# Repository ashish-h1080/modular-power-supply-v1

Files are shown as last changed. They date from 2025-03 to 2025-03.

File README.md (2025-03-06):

# ModuloVolt (V1.02) - modular power supply 
This modular power supply circuit provides selectable fixed and adjustable voltage outputs using LM2596 regulators. It integrates a 555 timer-based pulse generator and supports multiple operational modes via switchable configurations. The design includes high-side switching for improved isolation and safety.

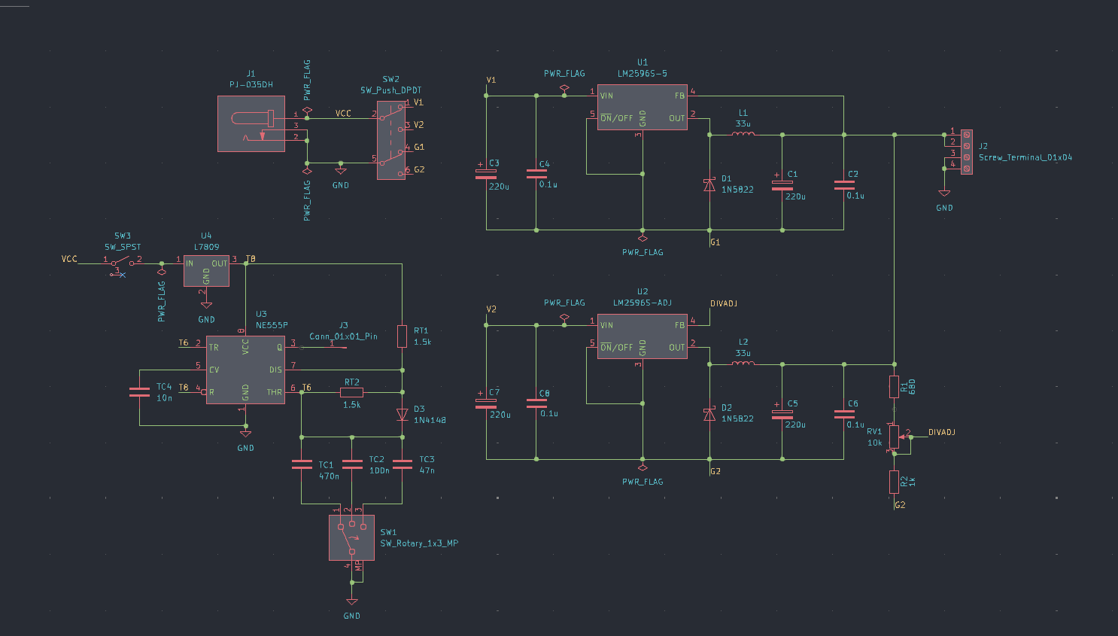
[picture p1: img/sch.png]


## Features
This modular power supply system offers a range of features designed for flexibility and reliability. It provides switchable voltage outputs, including a fixed 5V regulated supply using the LM2596-5V and an adjustable output of up to 12V via the LM2596-ADJ, controlled by a potentiometer. To ensure proper isolation and seamless switching between these voltage sources, a high-side DPDT switch is integrated into the design. Additionally, the system includes an integrated pulse generator, utilizing a 555 timer circuit to produce clock pulses. The pulse frequency can be adjusted by selecting different capacitors, making the system adaptable for various applications requiring precise timing signals.

## Implementation
The modular power supply system is designed for versatility and stability, incorporating key components for power input, regulation, filtering, and additional functionalities. A DC power jack (J1) serves as the main input source, while a DPDT switch (SW2) allows seamless selection between a fixed and an adjustable voltage regulator. The LM2596-5V (U1) ensures a stable 5V output, whereas the LM2596-ADJ (U2), controlled via a 10k potentiometer (RV1), provides a user-defined adjustable voltage. To enhance performance, capacitors (C1-C8) and inductors (L1, L2) are implemented for stability and noise reduction, while Schottky diodes (D1, D2) safeguard the system against reverse voltage. Additionally, a 555 timer (U3) functions as a pulse generator, with its frequency adjustable through capacitors (TC1-TC4) and resistors (RT1, RT2). The generated clock pulses are accessible via a single-pin connector (J3), offering expanded utility for various applications. Finally, a 4 pin terminal block (J2) efficiently distributes power and ground, ensuring easy connectivity for external circuits.

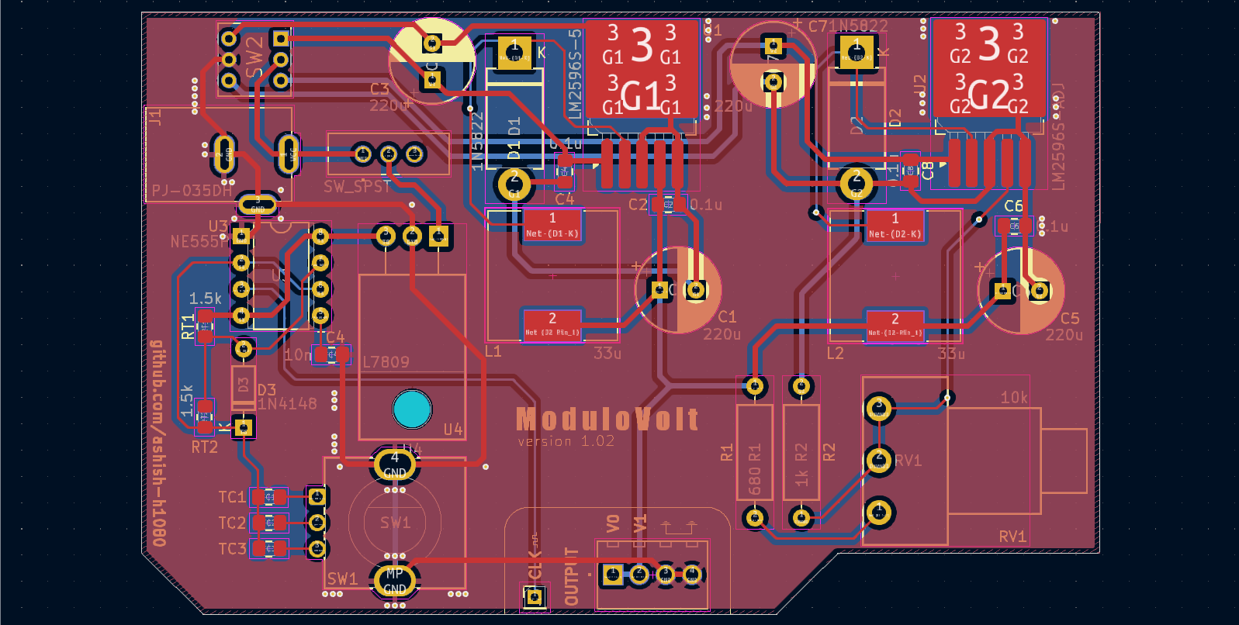
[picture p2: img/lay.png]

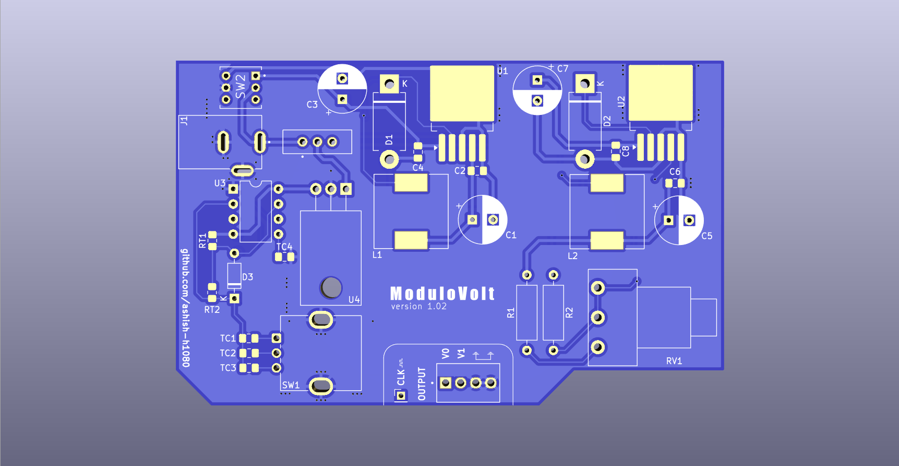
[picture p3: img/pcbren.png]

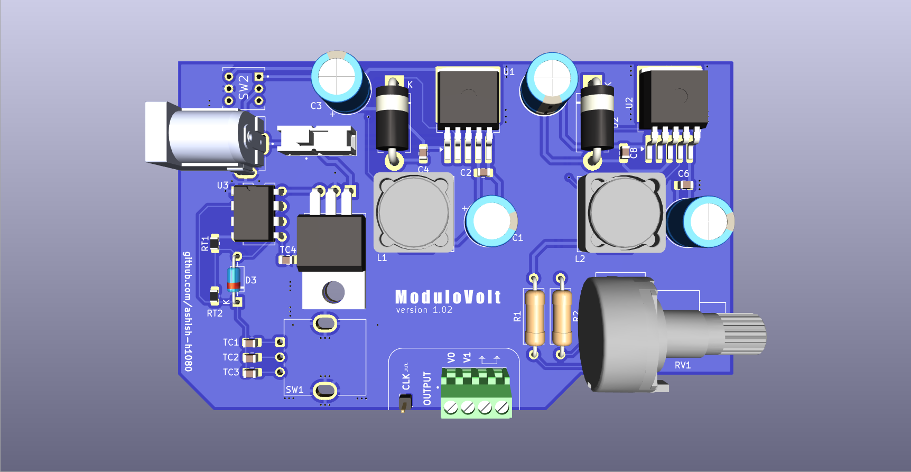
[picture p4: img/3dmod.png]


## Future Iterations
- **Onboard volt meter**
- **Additional signal processing (e.g., sine wave generator, filters, amplifiers)**
- **Microcontroller-based control for automated switching and monitoring**

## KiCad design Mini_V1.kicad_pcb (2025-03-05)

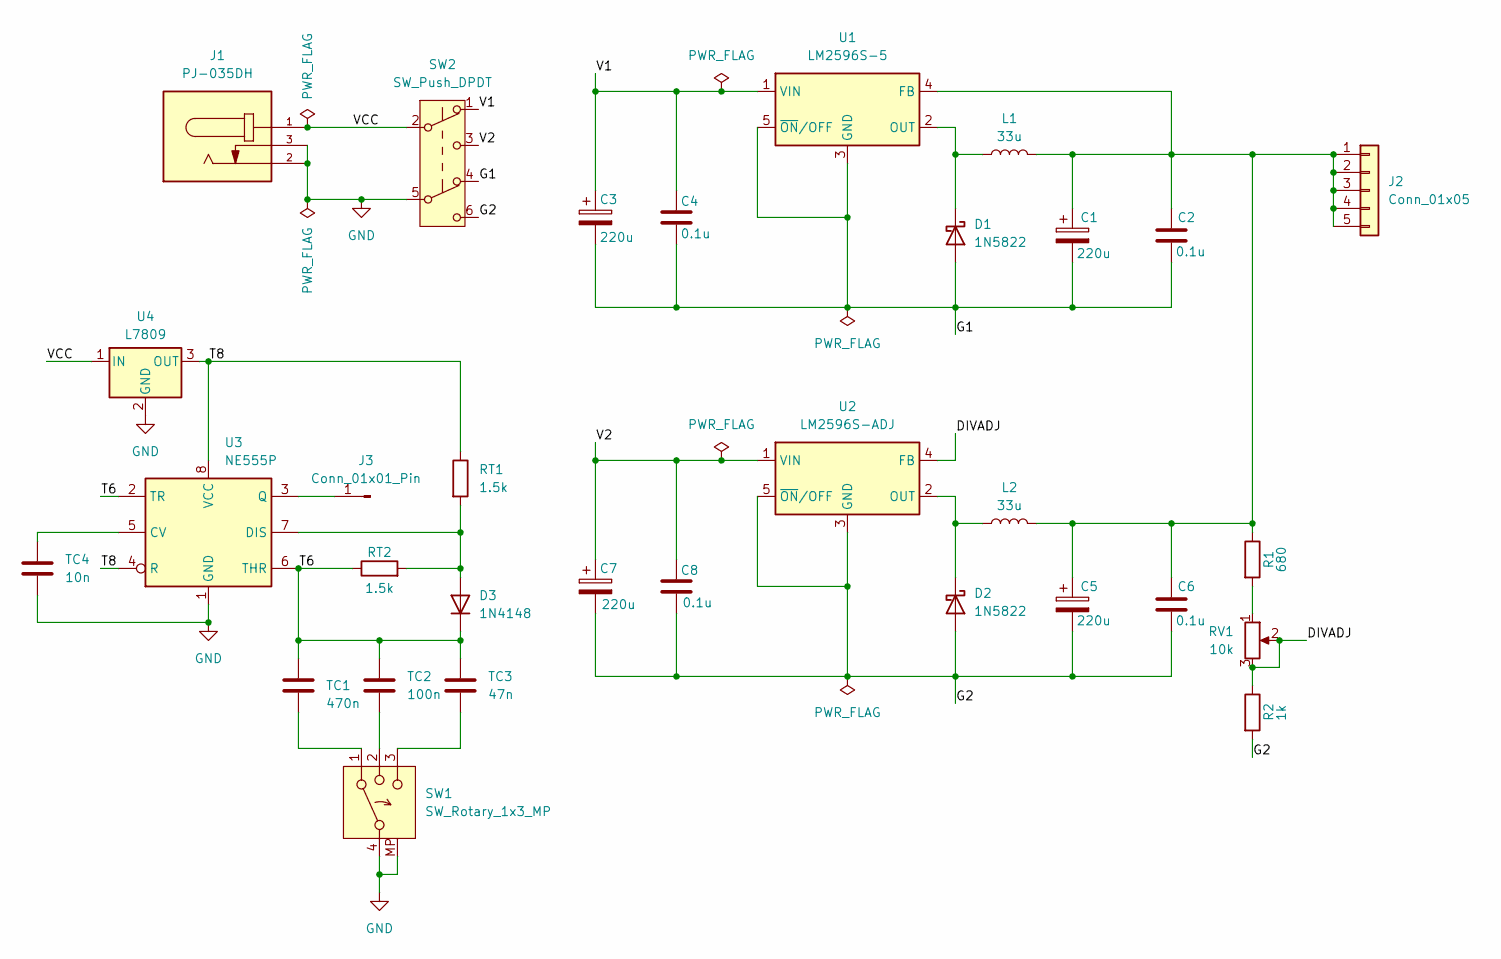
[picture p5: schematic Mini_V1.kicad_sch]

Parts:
C1, C3, C5, C7: 220u; CP_Radial_D8.0mm_P3.50mm
C2, C4, C6, C8: 0.1u; C_0805_2012Metric_Pad1.18x1.45mm_HandSolder
D1, D2: 1N5822; D_DO-201AD_P12.70mm_Horizontal
D3: 1N4148; D_DO-35_SOD27_P7.62mm_Horizontal
J1: PJ-035DH; CUI_PJ-035DH; PARTREV 1.05
J2: Conn_01x05; PinHeader_1x05_P2.00mm_Vertical
J3: Conn_01x01_Pin; PinHeader_1x01_P2.00mm_Vertical
L1, L2: 33u; INDP125125X600N
R1: 680; R_Axial_DIN0309_L9.0mm_D3.2mm_P12.70mm_Horizontal
R2: 1k; R_Axial_DIN0309_L9.0mm_D3.2mm_P12.70mm_Horizontal
RT1, RT2: 1.5k; R_0805_2012Metric_Pad1.20x1.40mm_HandSolder
RV1: 10k; Potentiometer_Piher_PC-16_Single_Horizontal
SW1: SW_Rotary_1x3_MP; RotaryEncoder_Bourns_Vertical_PEC12R-3x17F-Nxxxx(custom)
SW2: SW_Push_DPDT; SW_TL2230OAF140
TC1: 470n; C_0805_2012Metric_Pad1.18x1.45mm_HandSolder
TC2: 100n; C_0805_2012Metric_Pad1.18x1.45mm_HandSolder
TC3: 47n; C_0805_2012Metric_Pad1.18x1.45mm_HandSolder
TC4: 10n; C_0805_2012Metric_Pad1.18x1.45mm_HandSolder
U1: LM2596S-5; TO-263-5_TabPin3
U2: LM2596S-ADJ; TO-263-5_TabPin3
U3: NE555P; DIP-8_W7.62mm
U4: L7809; TO-220-3_Horizontal_TabDown

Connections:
/DIVADJ: R2.1, RV1.2, RV1.3, U2.4 (FB)
/G1: C1.2, C2.2, C3.2, C4.2, D1.2 (A), SW2.4 (A), U1.3 (GND), U1.5 (~ON/OFF)
/G2: C5.2, C6.2, C7.2, C8.2, D2.2 (A), R2.2, SW2.6 (C), U2.3 (GND), U2.5 (~ON/OFF)
/T6: D3.1 (K), RT2.1, TC1.1, TC2.1, TC3.1, U3.2 (TR), U3.6 (THR)
/T8: RT1.1, U3.4 (R), U3.8 (VCC), U4.3 (OUT)
/V1: C3.1, C4.1, SW2.1 (A), U1.1 (VIN)
/V2: C7.1, C8.1, SW2.3 (C), U2.1 (VIN)
/VCC: J1.1, SW2.2 (B), U4.1 (IN)
GND: J1.2, J1.3, SW1.4, SW1.MP, SW2.5 (B), TC4.2, U3.1 (GND), U4.2 (GND)
unnamed: D1.1 (K), L1.1, U1.2 (OUT)
unnamed: D2.1 (K), L2.1, U2.2 (OUT)
unnamed: D3.2 (A), RT1.2, RT2.2, U3.7 (DIS)
unnamed: C1.1, C2.1, C5.1, C6.1, J2.1, J2.2, J2.3, J2.4, J2.5, L1.2, L2.2, R1.1, U1.4 (FB)
unnamed: J3.1, U3.3 (Q)
unnamed: R1.2, RV1.1
unnamed: SW1.1, TC1.2
unnamed: SW1.2, TC2.2
unnamed: SW1.3, TC3.2
unnamed: TC4.1, U3.5 (CV)

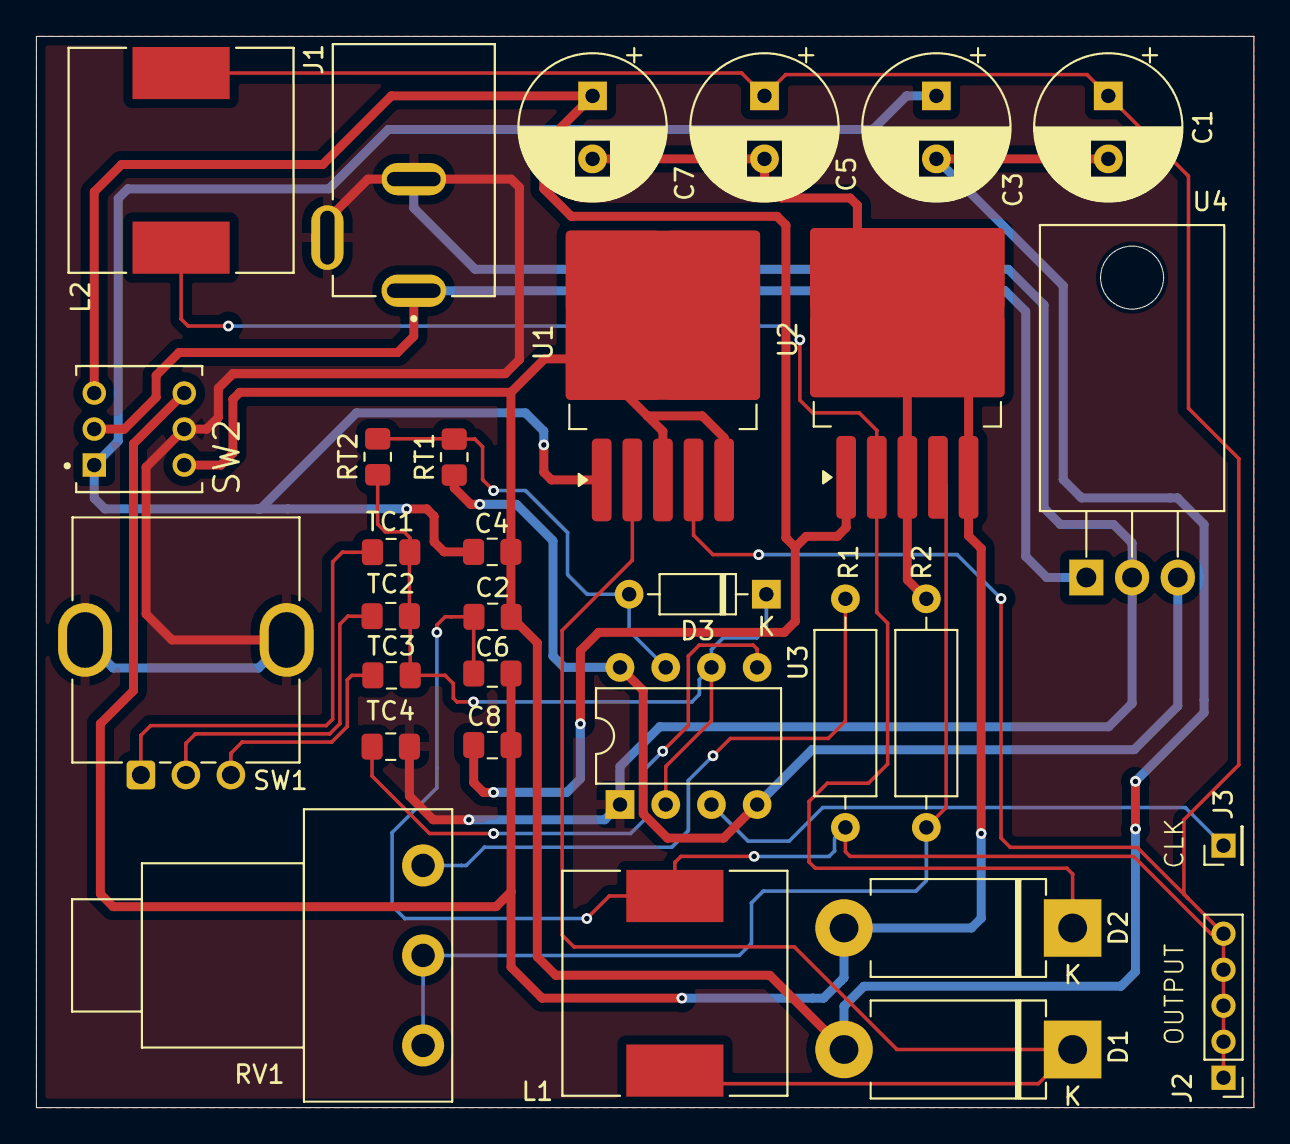
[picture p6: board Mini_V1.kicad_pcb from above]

Board: 2 copper layers, 67.6 x 59.5 mm, 31 parts (0 on the bottom side), 19 nets.
